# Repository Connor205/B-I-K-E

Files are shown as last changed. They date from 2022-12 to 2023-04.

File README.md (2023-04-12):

# ECE Capstone Spring 2023: B-I-K-E
**Best in Kard Entertainment**
Members: 
<ul>
<li>Sharwin Patil (CECS)</li>
<li>Connor Nelson (CECS)</li>
<li>Chris Swagler (CECS)</li>
<li>Tyler Passerine (CECS)</li>
<li>Adin Moses (ECE)</li>
<li>Jackson Heun (EE + Physics)</li>
</ul>

# Update (April 11, 2023):
We won first place at the ECE Capstone Expo and impressed industry judges with our blend of hardware/software solutions.

# Project Description
Our goal is to build an automated robotic poker table that will handle most of the functions a human dealer would, such as shuffling, dealing, and facilitating the game.

## Technology Stack
### Raspberry Pi 4B
The main compute for the B-I-K-E Poker Table is a Rasperry Pi 4B. The Pi is operating on native Ubuntu and will run our main program written in Python (3.10.6). The main program will facilitate the Poker logic and delegate low-level control to Arduino Unos and a Nucleo 32 via serial connection.
### Arduino Unos
The Unos will control motors and sensors for both the Card-Turret and Auto-Shuffler. A custom communication layer lies between the Arduinos and the Pi to ensure correct command execution and completion. Each Arduino is running C++ utilizing our own custom-built Stepper-Motor Controller Library.
### Arduino Nano
The Nano handles I/O control for the 4 button panels which enable players to provide input when playing Poker. Each button panel offers an I/O chip equipped with I2C and an interrupt pin. Our custom interfacing code translates the data over I2C into poker inputs for the Pi to operate upon.

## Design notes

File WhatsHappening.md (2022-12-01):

# So What the Actual Fk is Going On

Thats a fantastic question. Lets break down what actually needs to happen and what will be living in which places inside of the repository.

What are the different parts of the project?

- Arduino Code.
  - This code will live and run on an arduino that commands a variety of motors
  - It will be a worker bee for all intensive purposes
  - There may be multiple arduinos to manage various tasks at different points
    - Shuffle
    - Deal
    - Move
- Python Code
  - Main goal of this code is to manage the arduinos
  - It will keep track of where the various decks are located along with the current state of the game
  - It will take commands from some sort of user connected interface
    - Most likely it will host some sort of web server that will be running and processing requests
  - This is the brains of the entire table, it will be dispatching commands to various arduinos and managing all of the serial communication
- Front End
  - This will display the current game state
  - Will probably have some sort of web socket connection to the main python program
  - The web socket will allow some 2 way communication
  - That communication will update the state on the frontend and as such change the rendering
  - This probably needs to be mobile friendly, in that we need to be able to display this on a touchscreen that is not particularly large and located inside the table

Now here is what I am expected to actually happen. We will write the cpp code for the arduino as we are able to and as the motor and physical design is established.
In regards to the python code, there really isn't a ton of lines to write here. Simply we need to understand the flow of the cards and create and manage our classes as such. The hard part will be managing multiple arduinos. But we should be able to port over the code from chess bot. This will allow us to create some unique classes for each individual arduino.

It makes sense to have some sort of overarching table class to manage all of this. This table class will contain the individual arduinos and provide top level methods for our APIs to call when they need to. This probably gets built last. Most of this code is simply hardware descriptive in that we will be changing and altering it as the functionality and physical design of the table itself changes.

What would be incredibly useful is some sort of build script that goes in and builds all of the arduino code uploads it and then starts the python running and the webservers.

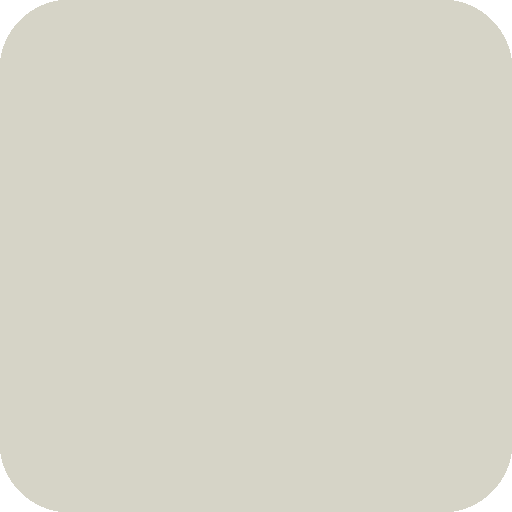
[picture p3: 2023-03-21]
Python/img/popup.png

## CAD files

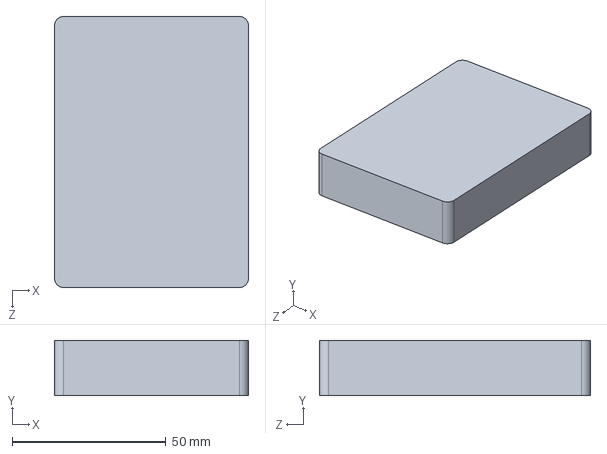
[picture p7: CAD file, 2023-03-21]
CAD/FullDeck.SLDPRT
63.0 x 18.0 x 88.0 mm

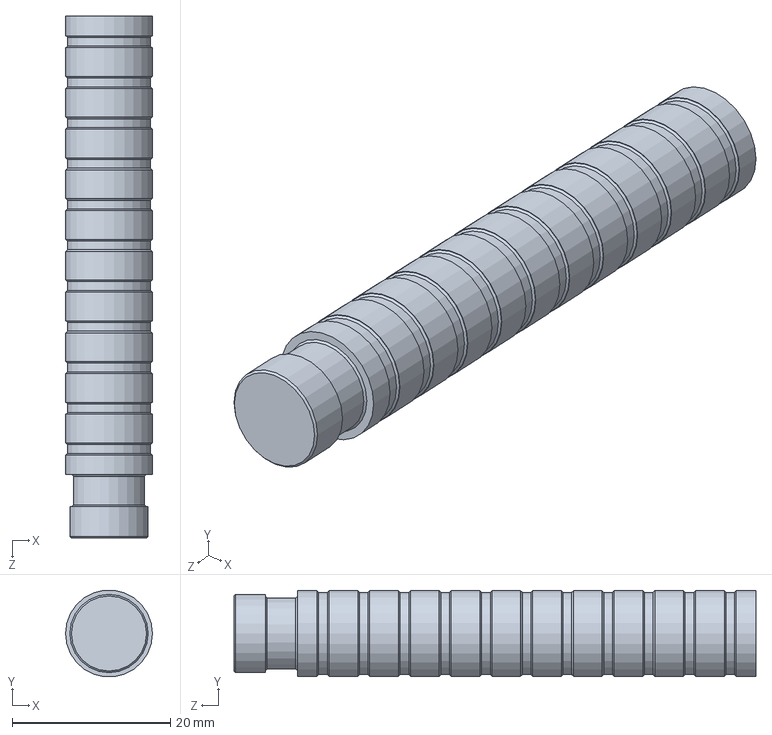
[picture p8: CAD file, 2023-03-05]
CAD/Turret/Roller.SLDPRT
11.0 x 10.9 x 66.0 mm

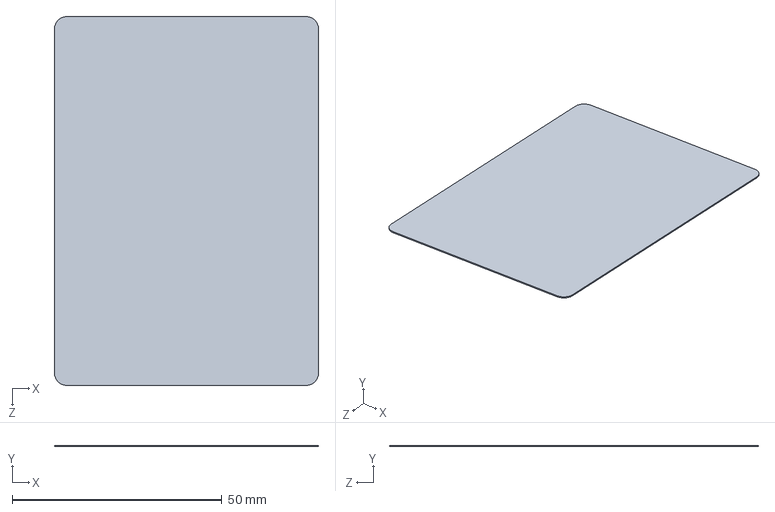
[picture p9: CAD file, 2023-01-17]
CAD/SinglePlayingCard.SLDPRT
63.0 x 0.35 x 88.0 mm

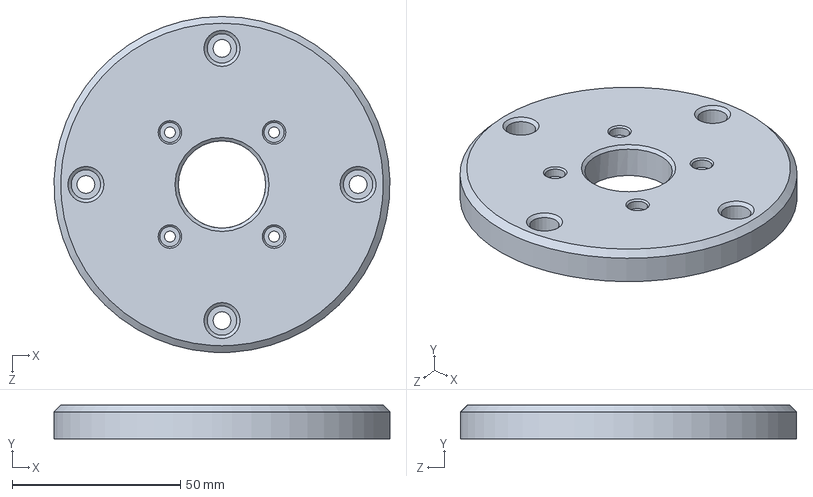
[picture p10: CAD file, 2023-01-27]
CAD/Turret/TurretStationaryBase.SLDPRT
100.0 x 10.0 x 100.0 mm

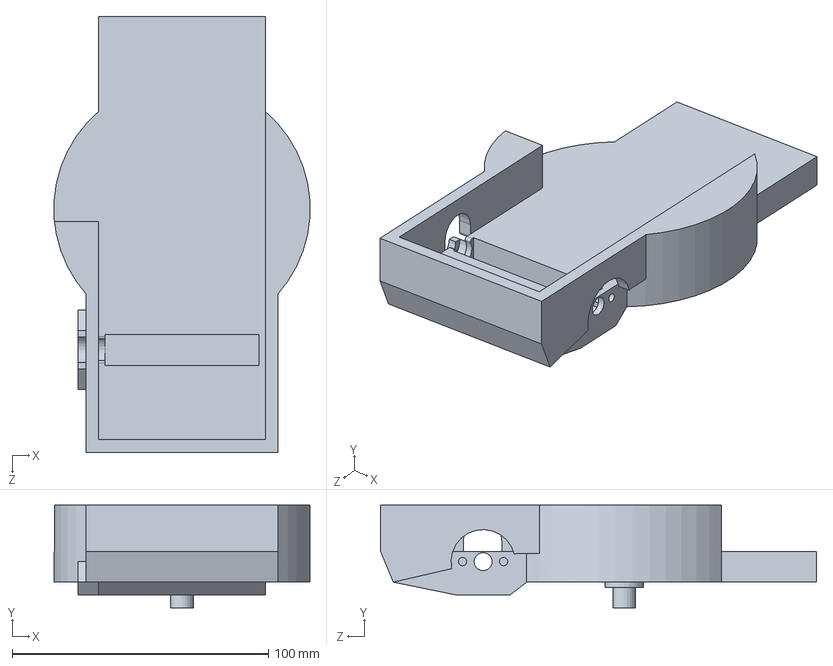
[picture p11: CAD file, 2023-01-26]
CAD/Turret/TurretRotatingBase.SLDPRT
99.8 x 40.0 x 170.0 mm

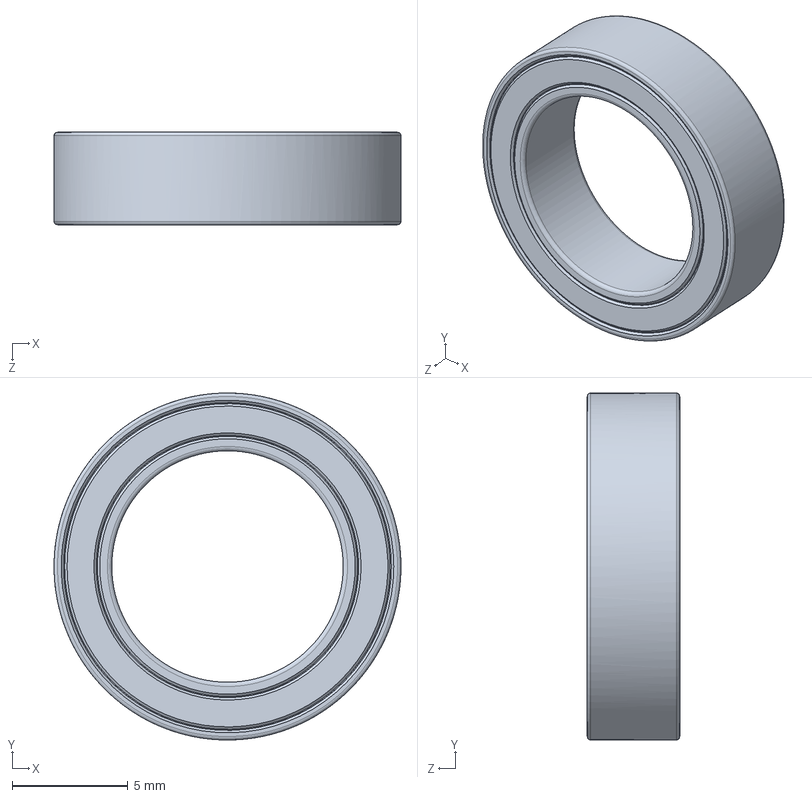
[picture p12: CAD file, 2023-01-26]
CAD/Turret/4668K252_10mm_Ball Bearing.SLDPRT
15.0 x 15.0 x 4.00 mm

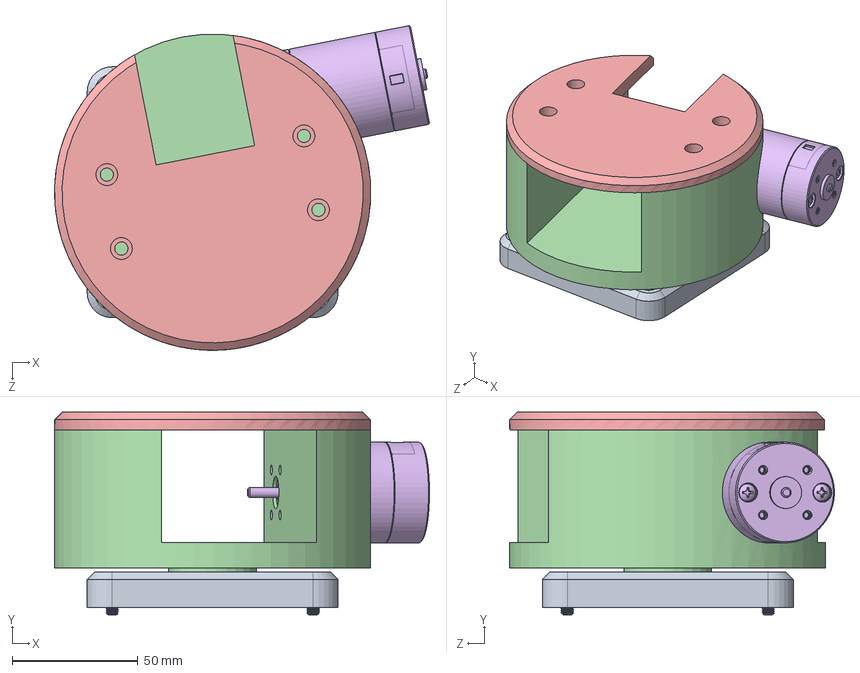
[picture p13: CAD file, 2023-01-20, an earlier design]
CAD/Turret/OldParts/TurretFullAssembly.SLDASM
149.4 x 80.7 x 129.4 mm
TurretMountingPlate
5972K365_Ball Bearing
91292A125_18-8 Stainless Steel Socket Head Screw x 4
TurretBearingMount
TurretBearingRoof
6331K12_Compact Round-Face DC Motor

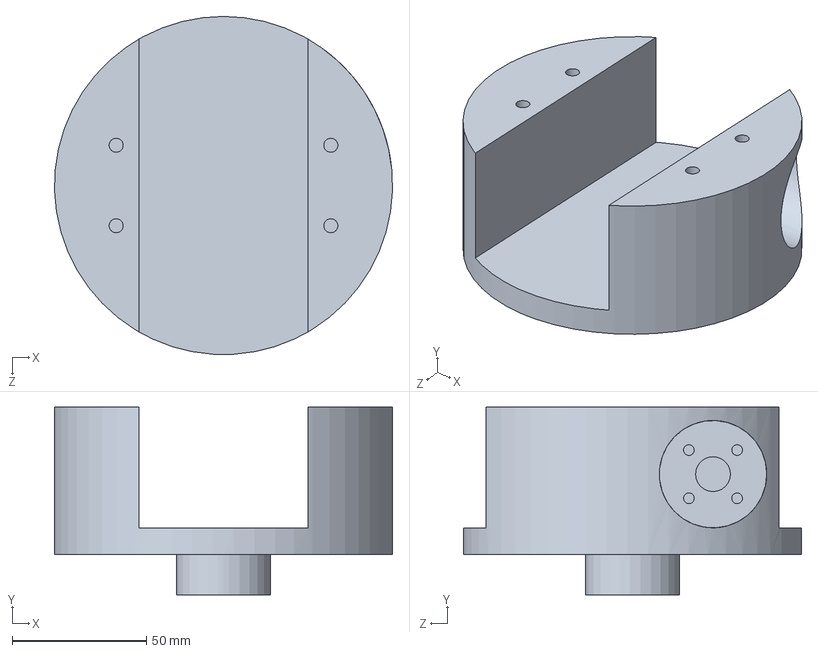
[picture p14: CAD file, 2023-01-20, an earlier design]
CAD/Turret/OldParts/TurretBearingMount.SLDPRT
125.9 x 70.0 x 126.0 mm

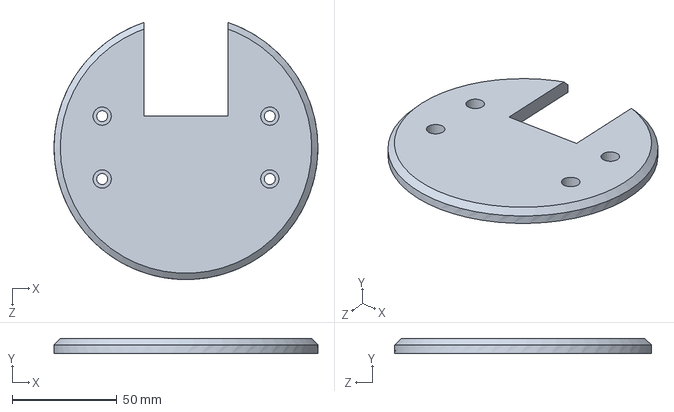
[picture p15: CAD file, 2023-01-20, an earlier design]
CAD/Turret/OldParts/TurretBearingRoof.SLDPRT
126.0 x 7.00 x 122.7 mm

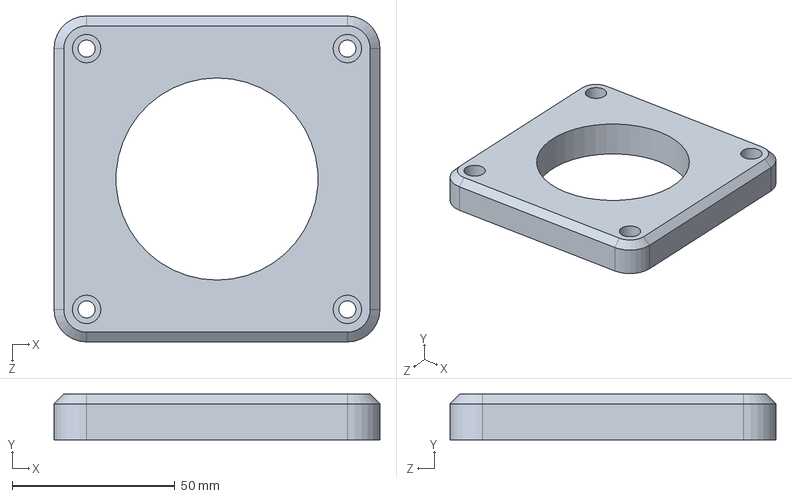
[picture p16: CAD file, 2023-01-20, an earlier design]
CAD/Turret/OldParts/TurretMountingPlate.SLDPRT
100.0 x 14.0 x 100.0 mm

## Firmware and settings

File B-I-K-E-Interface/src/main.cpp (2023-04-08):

#include <Arduino.h>
#include <Wire.h>
// #include <Pca9554.h>

/*
PCA9554 Addressing (These may be incorrect)
Address     A2  A1  A0
0x20        L   L   L
0x21        L   L   H
0x22        L   H   L
0x23        L   H   H
0x24        H   L   L
0x25        H   L   H
0x26        H   H   L
0x27        H   H   H
*/

// Panel 1 is the leftmost panel (near the shuffler)
constexpr uint8_t PANEL_1_ADDRESS = 0x26; // L L H
constexpr uint8_t PANEL_2_ADDRESS = 0x27; // L L L
constexpr uint8_t PANEL_3_ADDRESS = 0x20; // H H H
constexpr uint8_t PANEL_4_ADDRESS = 0x25; // H L H

constexpr uint8_t PANEL_1_INTERRUPT_PIN = 2;
constexpr uint8_t PANEL_2_INTERRUPT_PIN = 3;
constexpr uint8_t PANEL_3_INTERRUPT_PIN = 4;
constexpr uint8_t PANEL_4_INTERRUPT_PIN = 5;

constexpr uint8_t PCA9554_REG_INP = 0;
constexpr uint8_t PCA9554_REG_OUT = 1;
constexpr uint8_t PCA9554_REG_POL = 2;
constexpr uint8_t PCA9554_REG_CTRL = 3;

int previousPanel1State = 255;
int previousPanel2State = 255;
int previousPanel3State = 255;
int previousPanel4State = 255;

void panel1Interrupt(void) {
    Serial.println("1");
    // int readData = readI2CRegister(PANEL_1_ADDRESS, PCA9554_REG_INP);
    // Serial.println("Read data: " + String(readData));
}

void panel2Interrupt(void) {
    Serial.println("2");
    // int readData = readI2CRegister(PANEL_2_ADDRESS, PCA9554_REG_INP);
    // Serial.println("Read data: " + String(readData));
}

void panel3Interrupt(void) {
    Serial.println("3");
    // int readData = readI2CRegister(PANEL_3_ADDRESS, PCA9554_REG_INP);
    // Serial.println("Read data: " + String(readData));
}

void panel4Interrupt(void) {
    Serial.println("4");
    // int readData = readI2CRegister(PANEL_4_ADDRESS, PCA9554_REG_INP);
    // Serial.println("Read data: " + String(readData));
}

void i2cScanner() {
    // Scan I2C bus for devices
    Serial.println("Scanning I2C bus...");
    byte error, address;
    int nDevices = 0;
    for (address = 1; address < 127; address++) {
        Wire.beginTransmission(address);
        error = Wire.endTransmission();
        if (error == 0) {
            Serial.print("I2C device found at address 0x");
            if (address < 16) {
                Serial.print("0");
            }
            Serial.println(address, HEX);
            nDevices++;
        } else if (error == 4) {
            Serial.print("Unknown error at address 0x");
            if (address < 16) {
                Serial.print("0");
            }
            Serial.println(address, HEX);
        }
    }
    if (nDevices == 0) {
        Serial.println("No I2C devices found");
    } else {
        Serial.println("done");
    }
    delay(5000);
}

void setupInterrupts() {
    // Set the interrupt pins to input mode
    pinMode(PANEL_1_INTERRUPT_PIN, INPUT);
    pinMode(PANEL_2_INTERRUPT_PIN, INPUT);
    pinMode(PANEL_3_INTERRUPT_PIN, INPUT);
    pinMode(PANEL_4_INTERRUPT_PIN, INPUT);
    Serial.println("Attaching interrupt handlers...");
    // Attach the interrupt handlers
    attachInterrupt(digitalPinToInterrupt(PANEL_1_INTERRUPT_PIN), panel1Interrupt, FALLING);
    attachInterrupt(digitalPinToInterrupt(PANEL_2_INTERRUPT_PIN), panel2Interrupt, FALLING);
    attachInterrupt(digitalPinToInterrupt(PANEL_3_INTERRUPT_PIN), panel3Interrupt, FALLING);
    attachInterrupt(digitalPinToInterrupt(PANEL_4_INTERRUPT_PIN), panel4Interrupt, FALLING);
}

/**
 * @brief Writes the given panel ID and button index to the serial port
 *        to be obtained by the main program in Python
 *
 * @param panelId the panel ID [0, 3]
 * @param buttonIndex the button index [0, 7]
 */
void writeButtonInfo(uint8_t panelId, uint8_t buttonIndex) {
    // TODO: Write to python using serial and
    // define how the data is formatted on the python side
    if (panelId == -1 || buttonIndex == -1) {
        return;
    }
    Serial.println("Button:" + String(panelId) + "," + String(buttonIndex));
}

/**
 * @brief Reads the given register from the given I2C address
 *
 * @param i2cAddress the I2C address of the device
 * @param reg the address of the register to read
 * @return int the value of the register
 */
int readI2CRegister(uint8_t i2cAddress, uint8_t reg) {
    int value = 255; // Default to 255 so we default to no buttons pressed
    Wire.beginTransmission(i2cAddress);
    Wire.write(reg);
    uint8_t error = Wire.endTransmission();
    if (error == 0) {
        Wire.requestFrom(i2cAddress, (uint8_t)1);
        while (Wire.available() < 1)
            ;
        value = Wire.read();
    }
    // else {
    //   Serial.print("Error reading register at address 0x" + String(i2cAddress, HEX) + ": ");
    //   Serial.println(error);
    // }
    return value;
}

/**
 * @brief Given a panelValue, return the index of the button that was pressed
 * @note The buttons are indexed from [0, 7] where each one represents a bit in the full 8-bit representation
 *      of the panel value. For example, if the panel value is 1111 1110, then the button at index 0 was pressed.
 *
 * @param panelValue the value of the panel as an integer
 * @return uint8_t the index of the button that was pressed
 */
uint8_t getButtonIndex(uint8_t panelValue) {
    // We do this by finding the first 0 in the binary representation of the panel value
    for (uint8_t i = 7; i >= 0; i--) {
        if (panelValue % 2 == 0) {
            return i;
        } else {
            panelValue = panelValue >> 1;
        }
    }
    return -1;
}

void getAllPanelValues(bool print = false) {
    // Read the input register of each panel
    int panel1Value = readI2CRegister(PANEL_1_ADDRESS, PCA9554_REG_INP);
    int panel2Value = readI2CRegister(PANEL_2_ADDRESS, PCA9554_REG_INP);
    int panel3Value = readI2CRegister(PANEL_3_ADDRESS, PCA9554_REG_INP);
    int panel4Value = readI2CRegister(PANEL_4_ADDRESS, PCA9554_REG_INP);
    if (print) {
        Serial.println("Panel 1: " + String(panel1Value) + " | " + "Panel 2: " + String(panel2Value) + " | "
            + "Panel 3: " + String(panel3Value) + " | " + "Panel 4: " + String(panel4Value));
    }
    // Check if any buttons have been pressed, default value is 255
    int panelIndex = -1;
    int buttonIndex = -1;
    // Check if any buttons have been pressed (only one button can be pressed at a time)
    if (panel1Value != 255 && previousPanel1State == 255) {
        panelIndex = 0;
        buttonIndex = getButtonIndex(panel1Value);
        writeButtonInfo(panelIndex, buttonIndex);
    }
    if (panel2Value != 255 && previousPanel2State == 255) {
        panelIndex = 1;
        buttonIndex = getButtonIndex(panel2Value);
        writeButtonInfo(panelIndex, buttonIndex);
    }
    if (panel3Value != 255 && previousPanel3State == 255) {
        panelIndex = 2;
        buttonIndex = getButtonIndex(panel3Value);
        writeButtonInfo(panelIndex, buttonIndex);
    }
    if (panel4Value != 255 && previousPanel4State == 255) {
        panelIndex = 3;
        buttonIndex = getButtonIndex(panel4Value);
        writeButtonInfo(panelIndex, buttonIndex);
    }
    // Update the previous states
    previousPanel1State = panel1Value;
    previousPanel2State = panel2Value;
    previousPanel3State = panel3Value;
    previousPanel4State = panel4Value;
}

void setup() {
    // Start Serial
    Serial.begin(115200);
    // Serial.println("Initializing I2C bus...");
    // Serial.println(F("\nI2C PINS"));
    // Serial.print(F("\tSDA = "));
    // Serial.println(SDA);
    // Serial.print(F("\tSCL = "));
    // Serial.println(SCL);
    // Serial.println();
    Wire.begin();
    // setupInterrupts();
}

void loop() {
    getAllPanelValues(false);
    delay(20);
}

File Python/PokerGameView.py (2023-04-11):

import pygame
import random
import logging
import sys
from PokerGameModel import PokerGameModel
from Sprites import *
from Card import Card
from Enums import *


class PokerGameView:
    # CONSTANTS
    FONT_PATH = "fonts/Designer.otf"
    FONT_COLOR = (0, 0, 0)
    POPUP_FONT_COLOR = (0, 0, 0)
    # Sizes denote the actual sizes/lengths
    # Positions denote the center of the object at a coordinate

    # Boundaries
    # Full monitor size: 1920x1080
    # Desired resolution: 1280x720
    SCREEN_SIZE = [1280, 720]
    TABLE_SIZE = [int(SCREEN_SIZE[0]), SCREEN_SIZE[1]]
    MENU_SIZE = [int(SCREEN_SIZE[0] * 1/5), SCREEN_SIZE[1]]
    POPUP_SIZE = [int(0.7 * SCREEN_SIZE[1]), int(0.5 * SCREEN_SIZE[1])]

    # Sizes
    # Keeping it slightly to scale, table width is 60 inches, 
    # say card height is 5 inches and width is 2/3 of that
    CARD_SIZE = [int(TABLE_SIZE[0] * (5*2/3)/60), int(TABLE_SIZE[0] * 5/60)]
    FONT_HEIGHT = int(0.03 * TABLE_SIZE[1])
    POPUP_FONT_HEIGHT = int(0.1 * POPUP_SIZE[1])

    # Positions
    POPUP_POSITION = [int(SCREEN_SIZE[0]/2), int(SCREEN_SIZE[1]/2)]
    MENU_CORNER_POSITION = [TABLE_SIZE[0], 0]
    MENU_CENTER_POSITION = [int(MENU_CORNER_POSITION[0] + MENU_SIZE[0]/2), int(MENU_CORNER_POSITION[1] + FONT_HEIGHT)]
    TURRET_POSITION = [int(0.5 * TABLE_SIZE[0]), int(0.1 * TABLE_SIZE[1])]
    BURN_POSITION = [int(TURRET_POSITION[0] - 2 * CARD_SIZE[0]), TURRET_POSITION[1]]
    DEAL_POSITION = [int(TURRET_POSITION[0] + 2 * CARD_SIZE[0]), TURRET_POSITION[1]]

    COMMUNITY_3_POSITION = [int(TURRET_POSITION[0] + 0 * CARD_SIZE[0]), int(TURRET_POSITION[1] + 0.17 * TABLE_SIZE[1])]
    COMMUNITY_2_POSITION = [int(COMMUNITY_3_POSITION[0] - 1.25 * CARD_SIZE[0]), COMMUNITY_3_POSITION[1]]
    COMMUNITY_1_POSITION = [int(COMMUNITY_2_POSITION[0] - 1.25 * CARD_SIZE[0]), COMMUNITY_3_POSITION[1]]
    COMMUNITY_4_POSITION = [int(COMMUNITY_3_POSITION[0] + 1.25 * CARD_SIZE[0]), COMMUNITY_3_POSITION[1]]
    COMMUNITY_5_POSITION = [int(COMMUNITY_4_POSITION[0] + 1.25 * CARD_SIZE[0]), COMMUNITY_3_POSITION[1]]

    POT_POSITION = [int(TURRET_POSITION[0]), int(COMMUNITY_3_POSITION[1] + 0.75 * CARD_SIZE[1])]

    # The hub positions are center positions of the 4 player hubs which will have several sprites
    PLAYER_1_HUB_POSITION = [int(TURRET_POSITION[0] - 0.3 * TABLE_SIZE[0]), int(TURRET_POSITION[1] + 0.1 * TABLE_SIZE[1])]
    PLAYER_1_NAME_POSITION = [int(PLAYER_1_HUB_POSITION[0]), int(PLAYER_1_HUB_POSITION[1] - 0.75 * CARD_SIZE[1])]
    PLAYER_1_CARD_1_POSITION = [int(PLAYER_1_HUB_POSITION[0] - 0.6 * CARD_SIZE[0]), int(PLAYER_1_HUB_POSITION[1])]
    PLAYER_1_CARD_2_POSITION = [int(PLAYER_1_HUB_POSITION[0] + 0.6 * CARD_SIZE[0]), int(PLAYER_1_HUB_POSITION[1])]
    PLAYER_1_STACK_POSITION = [int(PLAYER_1_HUB_POSITION[0]), int(PLAYER_1_HUB_POSITION[1] + 0.75 * CARD_SIZE[1])]
    PLAYER_1_BET_POSITION = [int(PLAYER_1_HUB_POSITION[0]), int(PLAYER_1_STACK_POSITION[1] + 1.25 * FONT_HEIGHT)]
    PLAYER_1_BLIND_POSITION = [int(PLAYER_1_HUB_POSITION[0]), int(PLAYER_1_NAME_POSITION[1] - 1.25 * FONT_HEIGHT)]

    PLAYER_2_HUB_POSITION = [int(TURRET_POSITION[0] - 0.12 * TABLE_SIZE[0]), int(TURRET_POSITION[1] + 0.45 * TABLE_SIZE[1])]
    PLAYER_2_NAME_POSITION = [int(PLAYER_2_HUB_POSITION[0]), int(PLAYER_2_HUB_POSITION[1] - 0.75 * CARD_SIZE[1])]
    PLAYER_2_CARD_1_POSITION = [int(PLAYER_2_HUB_POSITION[0] - 0.6 * CARD_SIZE[0]), int(PLAYER_2_HUB_POSITION[1])]
    PLAYER_2_CARD_2_POSITION = [int(PLAYER_2_HUB_POSITION[0] + 0.6 * CARD_SIZE[0]), int(PLAYER_2_HUB_POSITION[1])]
    PLAYER_2_STACK_POSITION = [int(PLAYER_2_HUB_POSITION[0]), int(PLAYER_2_HUB_POSITION[1] + 0.75 * CARD_SIZE[1])]
    PLAYER_2_BET_POSITION = [int(PLAYER_2_HUB_POSITION[0]), int(PLAYER_2_STACK_POSITION[1] + 1.25 * FONT_HEIGHT)]
    PLAYER_2_BLIND_POSITION = [int(PLAYER_2_HUB_POSITION[0]), int(PLAYER_2_NAME_POSITION[1] - 1.25 * FONT_HEIGHT)]

    PLAYER_3_HUB_POSITION = [int(TURRET_POSITION[0] + 0.12 * TABLE_SIZE[0]), int(TURRET_POSITION[1] + 0.45 * TABLE_SIZE[1])]
    PLAYER_3_NAME_POSITION = [int(PLAYER_3_HUB_POSITION[0]), int(PLAYER_3_HUB_POSITION[1] - 0.75 * CARD_SIZE[1])]
    PLAYER_3_CARD_1_POSITION = [int(PLAYER_3_HUB_POSITION[0] - 0.6 * CARD_SIZE[0]), int(PLAYER_3_HUB_POSITION[1])]
    PLAYER_3_CARD_2_POSITION = [int(PLAYER_3_HUB_POSITION[0] + 0.6 * CARD_SIZE[0]), int(PLAYER_3_HUB_POSITION[1])]
    PLAYER_3_STACK_POSITION = [int(PLAYER_3_HUB_POSITION[0]), int(PLAYER_3_HUB_POSITION[1] + 0.75 * CARD_SIZE[1])]
    PLAYER_3_BET_POSITION = [int(PLAYER_3_HUB_POSITION[0]), int(PLAYER_3_STACK_POSITION[1] + 1.25 * FONT_HEIGHT)]
    PLAYER_3_BLIND_POSITION = [int(PLAYER_3_HUB_POSITION[0]), int(PLAYER_3_NAME_POSITION[1] - 1.25 * FONT_HEIGHT)]

    PLAYER_4_HUB_POSITION = [int(TURRET_POSITION[0] + 0.3 * TABLE_SIZE[0]), int(TURRET_POSITION[1] + 0.1 * TABLE_SIZE[1])]
    PLAYER_4_NAME_POSITION = [int(PLAYER_4_HUB_POSITION[0]), int(PLAYER_4_HUB_POSITION[1] - 0.75 * CARD_SIZE[1])]
    PLAYER_4_CARD_1_POSITION = [int(PLAYER_4_HUB_POSITION[0] - 0.6 * CARD_SIZE[0]), int(PLAYER_4_HUB_POSITION[1])]
    PLAYER_4_CARD_2_POSITION = [int(PLAYER_4_HUB_POSITION[0] + 0.6 * CARD_SIZE[0]), int(PLAYER_4_HUB_POSITION[1])]
    PLAYER_4_STACK_POSITION = [int(PLAYER_4_HUB_POSITION[0]), int(PLAYER_4_HUB_POSITION[1] + 0.75 * CARD_SIZE[1])]
    PLAYER_4_BET_POSITION = [int(PLAYER_4_HUB_POSITION[0]), int(PLAYER_4_STACK_POSITION[1] + 1.25 * FONT_HEIGHT)]
    PLAYER_4_BLIND_POSITION = [int(PLAYER_4_HUB_POSITION[0]), int(PLAYER_4_NAME_POSITION[1] - 1.25 * FONT_HEIGHT)]

    logger: logging.Logger
    model: PokerGameModel
    screen: pygame.Surface
    background: pygame.Surface
    backSprites: pygame.sprite.RenderUpdates # Sprite group for the background-related sprites
    burnSprites: pygame.sprite.RenderUpdates # Sprite group for the burn card sprites
    player1Sprites: pygame.sprite.RenderUpdates # Sprite group for non-card sprites of player 1
    player2Sprites: pygame.sprite.RenderUpdates # Sprite group for non-card sprites of player 2
    player3Sprites: pygame.sprite.RenderUpdates # Sprite group for non-card sprites of player 3
    player4Sprites: pygame.sprite.RenderUpdates # Sprite group for non-card sprites of player 4
    communitySprites: pygame.sprite.RenderUpdates # Sprite group for non-card sprites of the community cards
    player1CardSprites: pygame.sprite.RenderUpdates # Sprite group for card sprites of player 1
    player2CardSprites: pygame.sprite.RenderUpdates # Sprite group for card sprites of player 2
    player3CardSprites: pygame.sprite.RenderUpdates # Sprite group for card sprites of player 3
    player4CardSprites: pygame.sprite.RenderUpdates # Sprite group for card sprites of player 4
    communityCardSprites: pygame.sprite.RenderUpdates # Sprite group for card sprites of the community cards
    menuSprites: pygame.sprite.RenderUpdates # Sprite group for the menu-related sprites
    popupSprites: pygame.sprite.RenderUpdates # Sprite group for the popup-related sprites
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

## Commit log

2023-01-17 Created cards
    [FullDeck.SLDPRT, SinglePlayingCard.SLDPRT]
2023-01-20 More CAD stuff
    [5972K365_Ball Bearing.SLDPRT, 6331K12_Compact Round-Face DC Motor.SLDPRT, 91292A124_18-8 Stainless Steel Socket Head Screw.SLDPRT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]
2023-01-24 CAD Folder
    [5972K197_5mm_Ball Bearing.SLDPRT, 5972K365_35mm_Ball Bearing.SLDPRT, FullAssemblyv2.SLDASM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]
2023-01-24 Created Turret Arduino project
2023-01-26 CAD in gitignore
    [5972K197_5mm_Ball Bearing.SLDPRT, 5972K365_35mm_Ball Bearing.SLDPRT, FullAssemblyv2.SLDASM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]
2023-01-26 Removed CAD folder
2023-01-26 Fixed CAD folder
    [4668K252_10mm_Ball Bearing.SLDPRT, 5972K197_5mm_Ball Bearing.SLDPRT, 5972K365_35mm_Ball Bearing.SLDPRT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]
2023-01-27 Added degree to steps
    [5972K365_Ball Bearing.SLDPRT, 6331K12_Compact Round-Face DC Motor.SLDPRT, 91292A124_18-8 Stainless Steel Socket Head Screw.SLDPRT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]
2023-02-04 Stub methods; create controller; fix imports
    [Deck.py, Player.py, PlayerHand.py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]
2023-02-05 Turret support for DC Motors
    [FullDeck.SLDPRT, Roller.SLDPRT]
2023-02-05 Finished StepperMotor and Added functions to Turret
2023-02-09 Wired enable pin
2023-02-09 Removed stepper motor kill power
2023-02-14 Added Vectors
    [Roller.SLDPRT]
2023-02-25 Adding in light sensor code
2023-02-28 Setting up button listeners
2023-03-05 Added *.SLDASM to gitignore
    [Roller.SLDPRT]
2023-03-10 Create menu panel; Replace old stubs with comments and add more
    [PokerGameView.py]
2023-03-12 Fix typing in constructors
    [Sprites.py]
2023-03-16 Changing constants to reflect new wiring
2023-03-17 Added constants and removed angle stepper motor code
2023-03-17 include arduino
2023-03-17 Removed gear ratio from stepper motor in shuffler
    [FullDeck.SLDPRT]
2023-03-20 Calibration code:
2023-03-20 Fixing calibration method
2023-03-20 Added safeguard for no button press
2023-03-23 Added confirmation button pins
2023-03-23 Tested HallEffect Sensor
2023-03-26 Comment for dropper motor
2023-03-28 Added reverse indexer method
    [main.cpp]
2023-03-28 Added interrupt debugging:
2023-03-29 Fix: Fixes from all nighter
    [Arduino.py, GUITester.py, main.cpp]
2023-03-30 Fixed constants and pins and directions for calibration
    [main.cpp]
2023-03-30 belt step/dir pins
2023-03-30 Verified all stepper motors are working
2023-03-30 Feat: Adding in all serial commands for shuffler, moving elevator stepper out of shuffler object
2023-03-30 Changed belt length value
2023-03-30 Changed interface to Arduino Nano and combined code into one file
2023-03-30 Changed board and verified SDA and SCL pins
2023-04-01 Change constructor to allow empty hole cards
2023-04-03 Wrote button index algo
2023-04-03 Created Interface Arduino in python
2023-04-04 Fix typing whoopsie with tuple
    [PokerRound.py]
2023-04-04 Fix: fixing shuffler pins, updating interface code
    [Interface.py, main.cpp]
2023-04-04 Print statements
2023-04-07 Feat: working dispense and buttons
2023-04-08 Changed confirmation button pin numbers
2023-04-09 Fix: Chaning default argument to list()
    [PlayerHand.py]
2023-04-09 Fix: solved bug that was generating duplicate hands for each card
    [PlayerHand.py, PokerGameController.py]
2023-04-09 Fix: adding error message to prevent it form happening again
    [PlayerHand.py]
2023-04-09 Revert filepaths; remove some debug prints
    [PokerGameView.py, PokerRound.py, Sprites.py]
2023-04-10 Fix: adding in sending of commands for community card dealing
    [Turret.py]
2023-04-10 Fix: fixing println
2023-04-10 fix: removing raiseError from invalid output
    [Arduino.py]
2023-04-10 deleted serial.print
2023-04-10 Fix: adding in logging
    [Arduino.py]
2023-04-10 Fix: removing 1 from the index of the player
    [Turret.py]
2023-04-10 Fix: casting to int
    [Interface.py]
2023-04-10 Fix: adding lock to model changes
    [PokerGameController.py]
